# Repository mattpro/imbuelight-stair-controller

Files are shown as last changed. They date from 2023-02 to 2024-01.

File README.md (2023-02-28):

# imbuelight-stair-controller

<!-- Improved compatibility of back to top link: See: https://github.com/othneildrew/Best-README-Template/pull/73 -->

<!--
*** Thanks for checking out the Best-README-Template. If you have a suggestion
*** that would make this better, please fork the repo and create a pull request
*** or simply open an issue with the tag "enhancement".
*** Don't forget to give the project a star!
*** Thanks again! Now go create something AMAZING! :D
-->

<!-- PROJECT SHIELDS -->
<!--
*** I'm using markdown "reference style" links for readability.
*** Reference links are enclosed in brackets [ ] instead of parentheses ( ).
*** See the bottom of this document for the declaration of the reference variables
*** for contributors-url, forks-url, etc. This is an optional, concise syntax you may use.
*** https://www.markdownguide.org/basic-syntax/#reference-style-links
-->
[][contributors-url]
[][forks-url]
[][stars-url]
[][issues-url]
[][license-url]
[][linkedin-url]

<!-- PROJECT LOGO -->
<br />
<div align="center">
  <a href="https://github.com/othneildrew/Best-README-Template">
    
  </a>

  <h3 align="center">Best-README-Template</h3>

  <p align="center">
    An awesome README template to jumpstart your projects!
    <br />
    <a href="https://github.com/othneildrew/Best-README-Template"><strong>Explore the docs »</strong></a>
    <br />
    <br />
    <a href="https://github.com/othneildrew/Best-README-Template">View Demo</a>
    ·
    <a href="https://github.com/othneildrew/Best-README-Template/issues">Report Bug</a>
    ·
    <a href="https://github.com/othneildrew/Best-README-Template/issues">Request Feature</a>
  </p>
</div>

<!-- TABLE OF CONTENTS -->
<details>
  <summary>Table of Contents</summary>
  <ol>
    <li>
      <a href="#about-the-project">About The Project</a>
      <ul>
        <li><a href="#built-with">Built With</a></li>
      </ul>
    </li>
    <li>
      <a href="#getting-started">Getting Started</a>
      <ul>
        <li><a href="#prerequisites">Prerequisites</a></li>
        <li><a href="#installation">Installation</a></li>
      </ul>
    </li>
    <li><a href="#usage">Usage</a></li>
    <li><a href="#roadmap">Roadmap</a></li>
    <li><a href="#contributing">Contributing</a></li>
    <li><a href="#license">License</a></li>
    <li><a href="#contact">Contact</a></li>
    <li><a href="#acknowledgments">Acknowledgments</a></li>
  </ol>
</details>

<!-- ABOUT THE PROJECT -->
## About The Project

[Product Name Screen Shot](https://example.com)

There are many great README templates available on GitHub; however, I didn't find one that really suited my needs so I created this enhanced one. I want to create a README template so amazing that it'll be the last one you ever need -- I think this is it.

Here's why:
* Your time should be focused on creating something amazing. A project that solves a problem and helps others
* You shouldn't be doing the same tasks over and over like creating a README from scratch
* You should implement DRY principles to the rest of your life :smile:

Of course, no one template will serve all projects since your needs may be different. So I'll be adding more in the near future. You may also suggest changes by forking this repo and creating a pull request or opening an issue. Thanks to all the people have contributed to expanding this template!

Use the `BLANK_README.md` to get started.

<p align="right">(<a href="#readme-top">back to top</a>)</p>

### Built With

This section should list any major frameworks/libraries used to bootstrap your project. Leave any add-ons/plugins for the acknowledgements section. Here are a few examples.

* [][Next-url]
* [][React-url]
* [][Vue-url]
* [][Angular-url]
* [][Svelte-url]
* [][Laravel-url]
* [][Bootstrap-url]
* [][JQuery-url]

<p align="right">(<a href="#readme-top">back to top</a>)</p>

<!-- GETTING STARTED -->
## Getting Started

This is an example of how you may give instructions on setting up your project locally.
To get a local copy up and running follow these simple example steps.

### Prerequisites

This is an example of how to list things you need to use the software and how to install them.
* npm
  ```sh
  npm install npm@latest -g
  ```

### Installation

_Below is an example of how you can instruct your audience on installing and setting up your app. This template doesn't rely on any external dependencies or services._

1. Get a free API Key at [https://example.com](https://example.com)
2. Clone the repo
   ```sh
   git clone https://github.com/your_username_/Project-Name.git
   ```
3. Install NPM packages
   ```sh
   npm install
   ```
4. Enter your API in `config.js`
   ```js
   const API_KEY = 'ENTER YOUR API';
   ```

<p align="right">(<a href="#readme-top">back to top</a>)</p>

<!-- USAGE EXAMPLES -->
## Usage

Use this space to show useful examples of how a project can be used. Additional screenshots, code examples and demos work well in this space. You may also link to more resources.

_For more examples, please refer to the [Documentation](https://example.com)_

<p align="right">(<a href="#readme-top">back to top</a>)</p>

<!-- ROADMAP -->
## Roadmap

- [x] Add Changelog
- [x] Add back to top links
- [ ] Add Additional Templates w/ Examples
- [ ] Add "components" document to easily copy & paste sections of the readme
- [ ] Multi-language Support
    - [ ] Chinese
    - [ ] Spanish

See the [open issues](https://github.com/othneildrew/Best-README-Template/issues) for a full list of proposed features (and known issues).

<p align="right">(<a href="#readme-top">back to top</a>)</p>

<!-- CONTRIBUTING -->
## Contributing

Contributions are what make the open source community such an amazing place to learn, inspire, and create. Any contributions you make are **greatly appreciated**.

If you have a suggestion that would make this better, please fork the repo and create a pull request. You can also simply open an issue with the tag "enhancement".
Don't forget to give the project a star! Thanks again!

1. Fork the Project
2. Create your Feature Branch (`git checkout -b feature/AmazingFeature`)
3. Commit your Changes (`git commit -m 'Add some AmazingFeature'`)
4. Push to the Branch (`git push origin feature/AmazingFeature`)
5. Open a Pull Request

<p align="right">(<a href="#readme-top">back to top</a>)</p>

<!-- LICENSE -->
## License

Distributed under the MIT License. See `LICENSE.txt` for more information.

<p align="right">(<a href="#readme-top">back to top</a>)</p>

<!-- CONTACT -->
## Contact

Your Name - [@your_twitter](https://twitter.com/your_username) - email@example.com

Project Link: [https://github.com/your_username/repo_name](https://github.com/your_username/repo_name)

<p align="right">(<a href="#readme-top">back to top</a>)</p>

<!-- ACKNOWLEDGMENTS -->
## Acknowledgments

Use this space to list resources you find helpful and would like to give credit to. I've included a few of my favorites to kick things off!

* [Choose an Open Source License](https://choosealicense.com)
* [GitHub Emoji Cheat Sheet](https://www.webpagefx.com/tools/emoji-cheat-sheet)
* [Malven's Flexbox Cheatsheet](https://flexbox.malven.co/)
* [Malven's Grid Cheatsheet](https://grid.malven.co/)
* [Img Shields](https://shields.io)
* [GitHub Pages](https://pages.github.com)
* [Font Awesome](https://fontawesome.com)
* [React Icons](https://react-icons.github.io/react-icons/search)

<p align="right">(<a href="#readme-top">back to top</a>)</p>

<!-- MARKDOWN LINKS & IMAGES -->
<!-- https://www.markdownguide.org/basic-syntax/#reference-style-links -->
[contributors-shield]: https://img.shields.io/github/contributors/othneildrew/Best-README-Template.svg?style=for-the-badge
[contributors-url]: https://github.com/othneildrew/Best-README-Template/graphs/contributors
[forks-shield]: https://img.shields.io/github/forks/othneildrew/Best-README-Template.svg?style=for-the-badge
[forks-url]: https://github.com/othneildrew/Best-README-Template/network/members
[stars-shield]: https://img.shields.io/github/stars/othneildrew/Best-README-Template.svg?style=for-the-badge
[stars-url]: https://github.com/othneildrew/Best-README-Template/stargazers
[issues-shield]: https://img.shields.io/github/issues/othneildrew/Best-README-Template.svg?style=for-the-badge
[issues-url]: https://github.com/othneildrew/Best-README-Template/issues
[license-shield]: https://img.shields.io/github/license/othneildrew/Best-README-Template.svg?style=for-the-badge
[license-url]: https://github.com/othneildrew/Best-README-Template/blob/master/LICENSE.txt
[linkedin-shield]: https://img.shields.io/badge/-LinkedIn-black.svg?style=for-the-badge&logo=linkedin&colorB=555
[linkedin-url]: https://linkedin.com/in/othneildrew
[product-screenshot]: images/screenshot.png
[Next.js]: https://img.shields.io/badge/next.js-000000?style=for-the-badge&logo=nextdotjs&logoColor=white
[Next-url]: https://nextjs.org/
[React.js]: https://img.shields.io/badge/React-20232A?style=for-the-badge&logo=react&logoColor=61DAFB
[React-url]: https://reactjs.org/
[Vue.js]: https://img.shields.io/badge/Vue.js-35495E?style=for-the-badge&logo=vuedotjs&logoColor=4FC08D
[Vue-url]: https://vuejs.org/
[Angular.io]: https://img.shields.io/badge/Angular-DD0031?style=for-the-badge&logo=angular&logoColor=white
[Angular-url]: https://angular.io/
[Svelte.dev]: https://img.shields.io/badge/Svelte-4A4A55?style=for-the-badge&logo=svelte&logoColor=FF3E00
[Svelte-url]: https://svelte.dev/
[Laravel.com]: https://img.shields.io/badge/Laravel-FF2D20?style=for-the-badge&logo=laravel&logoColor=white
[Laravel-url]: https://laravel.com
[Bootstrap.com]: https://img.shields.io/badge/Bootstrap-563D7C?style=for-the-badge&logo=bootstrap&logoColor=white
[Bootstrap-url]: https://getbootstrap.com
[JQuery.com]: https://img.shields.io/badge/jQuery-0769AD?style=for-the-badge&logo=jquery&logoColor=white
[JQuery-url]: https://jquery.com

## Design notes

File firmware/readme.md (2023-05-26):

## Build in WSL

1. Make sure that env PICO_SDK_PATH is set

```
export PICO_SDK_PATH=../../pico-sdk
```

2. Make directory build 

```
mkdir build
```

3. Run cmake from build directory

```
cd build
cmake ..
```

Example from WSL terminal:
```
/mnt/d/LocalRepo/ImbueLight/imbuelight-stair-controller/firmware/imbuelight_stair_controller_fw/build$ cmake ..
```

4. Build project

```
make
```

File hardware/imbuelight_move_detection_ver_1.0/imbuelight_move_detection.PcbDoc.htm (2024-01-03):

Reporting Options

# File in Previous Format

Date | : | 24.12.2023
Time | : | 13:05:48
Filename | : | D:\LocalRepo\imbue_light\imbuelight-stair-controller\hardware\imbuelight_move_detection_ver_1.0\imbuelight_move_detection.PcbDoc

Version | Warning

This file was generated by an earlier version of the software

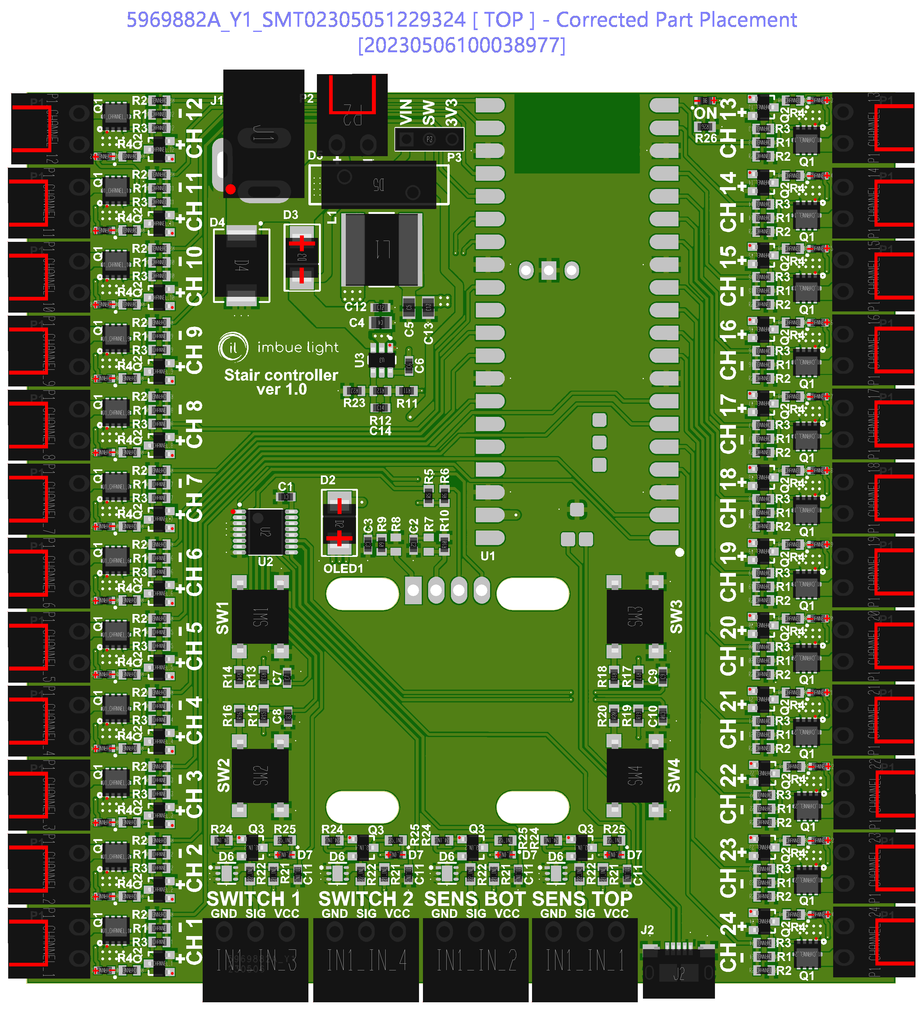
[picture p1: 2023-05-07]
hardware/Production/ver 1.0/Produce_DanZhi.SMT_Snapshot.Top.5969882A_Y1.SMT02305051229324.png

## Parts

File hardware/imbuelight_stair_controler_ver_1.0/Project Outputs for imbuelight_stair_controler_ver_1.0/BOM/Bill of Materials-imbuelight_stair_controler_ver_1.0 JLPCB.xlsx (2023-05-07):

Comment | Designator | Footprint | JLCPCB Part #（optional）
100nF 0603 50V | C1, C2, C3, C6, C7, C8, C9, C10, C11_IN_1, C11_IN_2, C11_IN_3, C11_IN_4, C12 | CAP_0603_High_density | C282519
10uF 0805 50V | C4 | CAP_0805_High_density | C440198
22uF 0805 50V | C5, C13 | CAP_0805_High_density | C98190
56pF 0603 50V | C14 | CAP_0603_High_density | C39148
C205450 | D1_Channel_1, D1_Channel_2, D1_Channel_3, D1_Channel_4, D1_Channel_5, D1_Channel_6, D1_Channel_7, D1_Channel_8, D1_Channel_9, D1_Channel_10, D1_Channel_11, D1_Channel_12, D1_Channel_13, D1_Channel_14, D1_Channel_15, D1_Channel_16, D1_Channel_17, D1_Channel_18, D1_Channel_19, D1_Channel_20, D1_Channel_21, D1_Channel_22, D1_Channel_23, D1_Channel_24, D8 | LED_0603 | C205450
SS24 | D2, D3 | DO214AA | C2845097
SMCJ15CA | D4 | DIOM7959X262N | C720069
C283933 | D5 | SIOV-S14K50 | C283933
C84266 | D7_IN_1, D7_IN_2, D7_IN_3, D7_IN_4 | LED_0603 | C84266
15EDGRC-3.5-3P | IN1_IN_1, IN1_IN_2, IN1_IN_3, IN1_IN_4 | 15EDGRC-3.5 - 3 PIN | C880573
PJ-202BH | J1 | CUI_PJ-202BH | C2851165
10118193-0001LF | J2 | 10118193-0001LF | C482361
NR8040T100M | L1 | INDP8080X42N | C168127
15EDGRC-3.5-2P | P1_Channel_1, P1_Channel_2, P1_Channel_3, P1_Channel_4, P1_Channel_5, P1_Channel_6, P1_Channel_7, P1_Channel_8, P1_Channel_9, P1_Channel_10, P1_Channel_11, P1_Channel_12, P1_Channel_13, P1_Channel_14, P1_Channel_15, P1_Channel_16, P1_Channel_17, P1_Channel_18, P1_Channel_19, P1_Channel_20, P1_Channel_21, P1_Channel_22, P1_Channel_23, P1_Channel_24, P2 | 15EDGRC-3.5 - 2 pin | C61791
HEADER_1X3_2.54_0DEG_THT | P3 | HDR1X3_2.54 | C5360899
AON7410 | Q1_Channel_1, Q1_Channel_2, Q1_Channel_3, Q1_Channel_4, Q1_Channel_5, Q1_Channel_6, Q1_Channel_7, Q1_Channel_8, Q1_Channel_9, Q1_Channel_10, Q1_Channel_11, Q1_Channel_12, Q1_Channel_13, Q1_Channel_14, Q1_Channel_15, Q1_Channel_16, Q1_Channel_17, Q1_Channel_18, Q1_Channel_19, Q1_Channel_20, Q1_Channel_21, Q1_Channel_22, Q1_Channel_23, Q1_Channel_24 | DFN3x3_8L | C269266
BC817-40LT1G | Q2_Channel_1, Q2_Channel_2, Q2_Channel_3, Q2_Channel_4, Q2_Channel_5, Q2_Channel_6, Q2_Channel_7, Q2_Channel_8, Q2_Channel_9, Q2_Channel_10, Q2_Channel_11, Q2_Channel_12, Q2_Channel_13, Q2_Channel_14, Q2_Channel_15, Q2_Channel_16, Q2_Channel_17, Q2_Channel_18, Q2_Channel_19, Q2_Channel_20, Q2_Channel_21, Q2_Channel_22, Q2_Channel_23, Q2_Channel_24, Q3_IN_1, Q3_IN_2, Q3_IN_3, Q3_IN_4 | SOT-23A | C94412
0603 10kOhm 1% | R1_Channel_1, R1_Channel_2, R1_Channel_3, R1_Channel_4, R1_Channel_5, R1_Channel_6, R1_Channel_7, R1_Channel_8, R1_Channel_9, R1_Channel_10, R1_Channel_11, R1_Channel_12, R1_Channel_13, R1_Channel_14, R1_Channel_15, R1_Channel_16, R1_Channel_17, R1_Channel_18, R1_Channel_19, R1_Channel_20, R1_Channel_21, R1_Channel_22, R1_Channel_23, R1_Channel_24, R2_Channel_1, R2_Channel_2, R2_Channel_3, R2_Channel_4, R2_Channel_5, R2_Channel_6, R2_Channel_7, R2_Channel_8, R2_Channel_9, R2_Channel_10, R2_Channel_11, R2_Channel_12, R2_Channel_13, R2_Channel_14, R2_Channel_15, R2_Channel_16, R2_Channel_17, R2_Channel_18, R2_Channel_19, R2_Channel_20, R2_Channel_21, R2_Channel_22, R2_Channel_23, R2_Channel_24, R5, R6, R13, R15, R17, R19, R21_IN_1, R21_IN_2, R21_IN_3, R21_IN_4 | RES_0603 | C3017715
0603 1kOhm 1% | R3_Channel_1, R3_Channel_2, R3_Channel_3, R3_Channel_4, R3_Channel_5, R3_Channel_6, R3_Channel_7, R3_Channel_8, R3_Channel_9, R3_Channel_10, R3_Channel_11, R3_Channel_12, R3_Channel_13, R3_Channel_14, R3_Channel_15, R3_Channel_16, R3_Channel_17, R3_Channel_18, R3_Channel_19, R3_Channel_20, R3_Channel_21, R3_Channel_22, R3_Channel_23, R3_Channel_24, R4_Channel_1, R4_Channel_2, R4_Channel_3, R4_Channel_4, R4_Channel_5, R4_Channel_6, R4_Channel_7, R4_Channel_8, R4_Channel_9, R4_Channel_10, R4_Channel_11, R4_Channel_12, R4_Channel_13, R4_Channel_14, R4_Channel_15, R4_Channel_16, R4_Channel_17, R4_Channel_18, R4_Channel_19, R4_Channel_20, R4_Channel_21, R4_Channel_22, R4_Channel_23, R4_Channel_24, R24_IN_1, R24_IN_2, R24_IN_3, R24_IN_4, R25_IN_1, R25_IN_2, R25_IN_3, R25_IN_4, R26 | RES_0603 | C3016283
RES_0_0402_1_1/16 | R9, R10 | RES_0603 | C21189
0603 49.9Ohm 1% | R11 | RES_0603 | C23185
0603 100kOhm 1% | R12 | RES_0603 | C25803
0603 10Ohm 1% | R14, R16, R18, R20, R22_IN_1, R22_IN_2, R22_IN_3, R22_IN_4 | RES_0603 | C22859
0603 22.1kOhm 1% | R23 | RES_0603 | C137768
SWITCH SMD | SW1, SW2, SW3, SW4 | B3FS-1010 | C231324
PCA9557PW,118 | U2 | TSOP65P640X120-16M | C141380
TPS54202DDCR | U3 | FP-DDC0006A-MFG | C191884

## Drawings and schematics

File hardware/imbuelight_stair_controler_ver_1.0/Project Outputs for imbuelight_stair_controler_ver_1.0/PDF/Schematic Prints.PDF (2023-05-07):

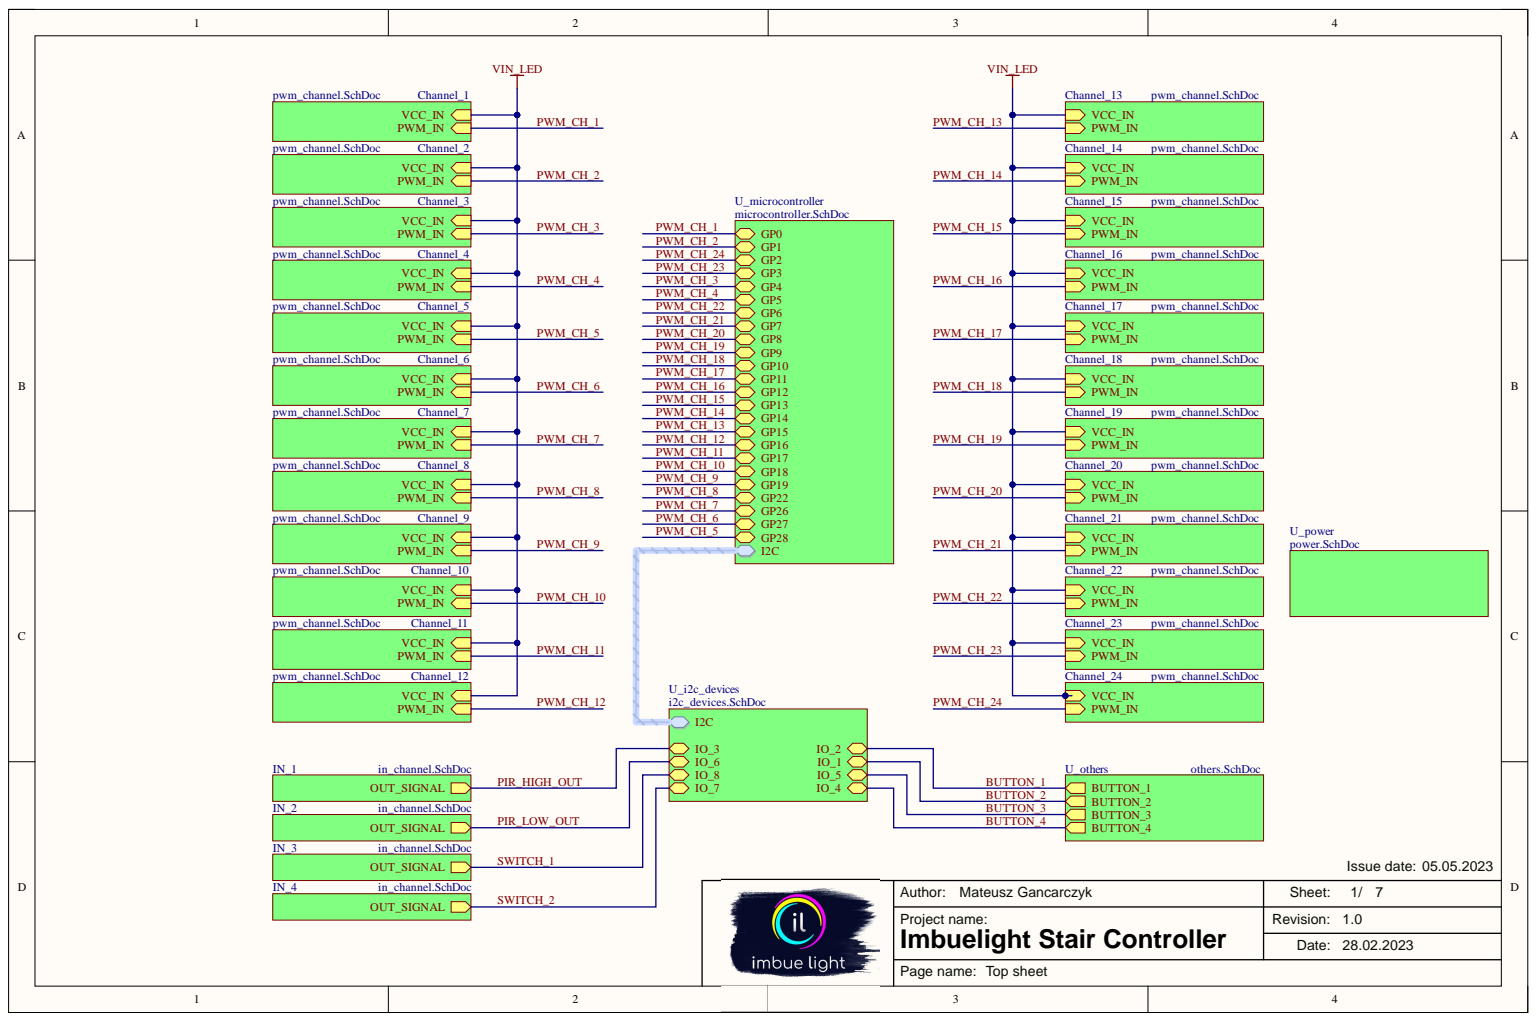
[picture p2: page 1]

OUT_SIGNAL | PIR_HIGH_OUT | BUTTON_1 | BUTTON_1 BUTTON_2 BUTTON_3 BUTTON_4

PIR_LOW_OUT | BUTTON_2

BUTTON_3

OUT_SIGNAL | | BUTTON_4

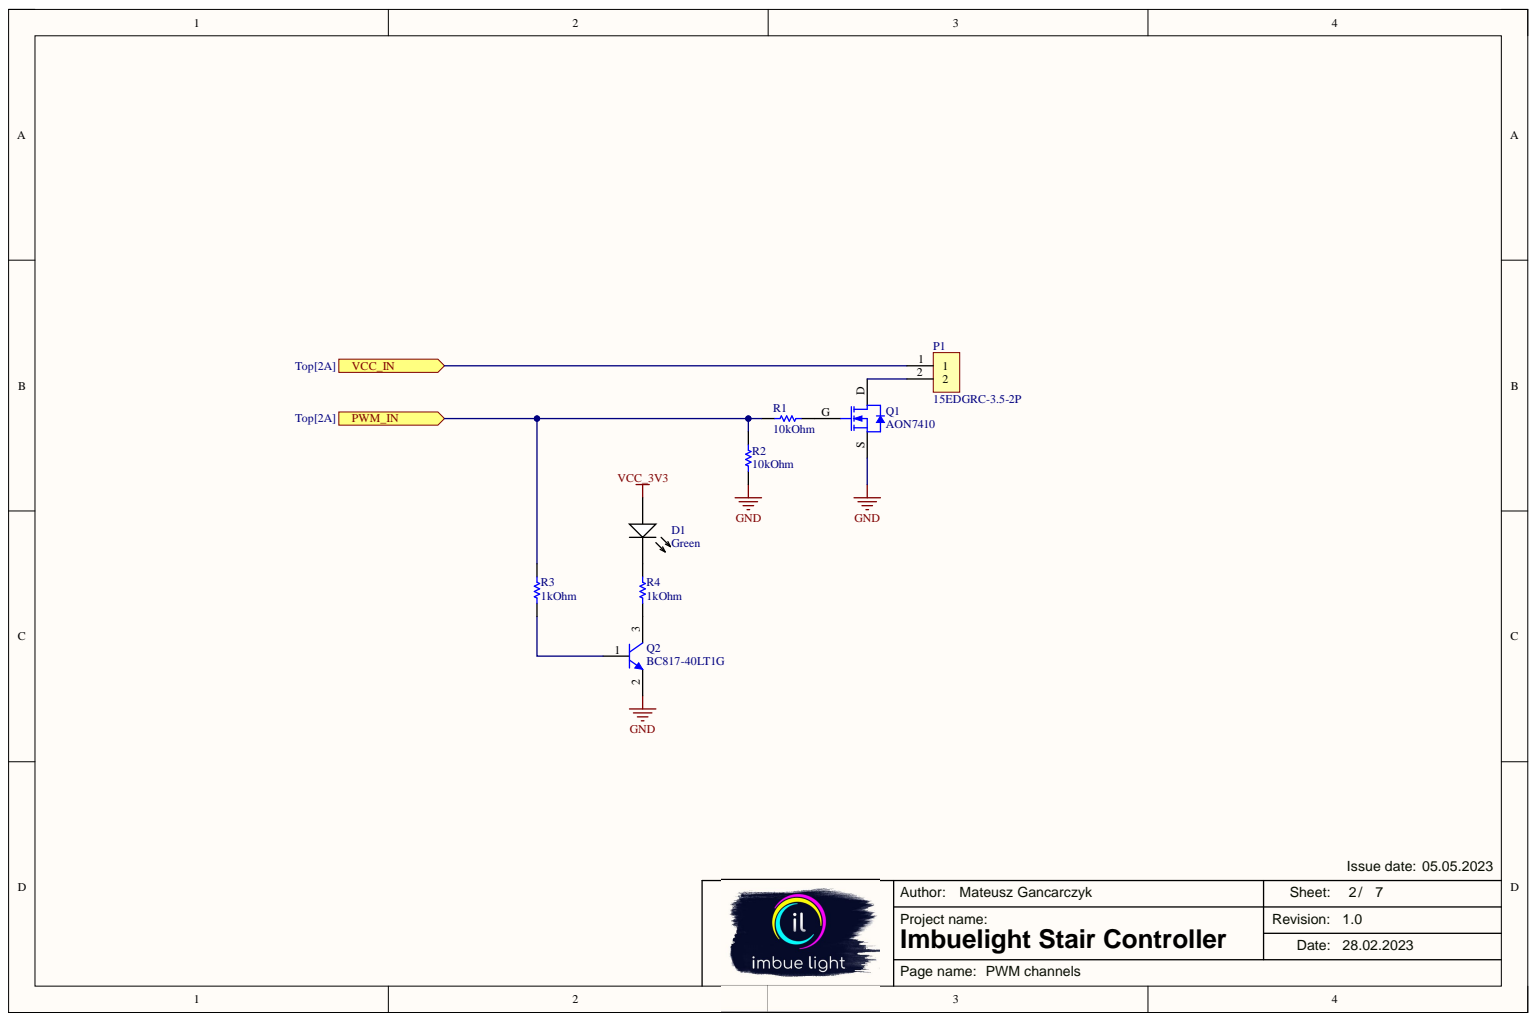
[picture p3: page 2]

Mateusz Gancarczyk
Imbuelight Stair Controller PWM channels

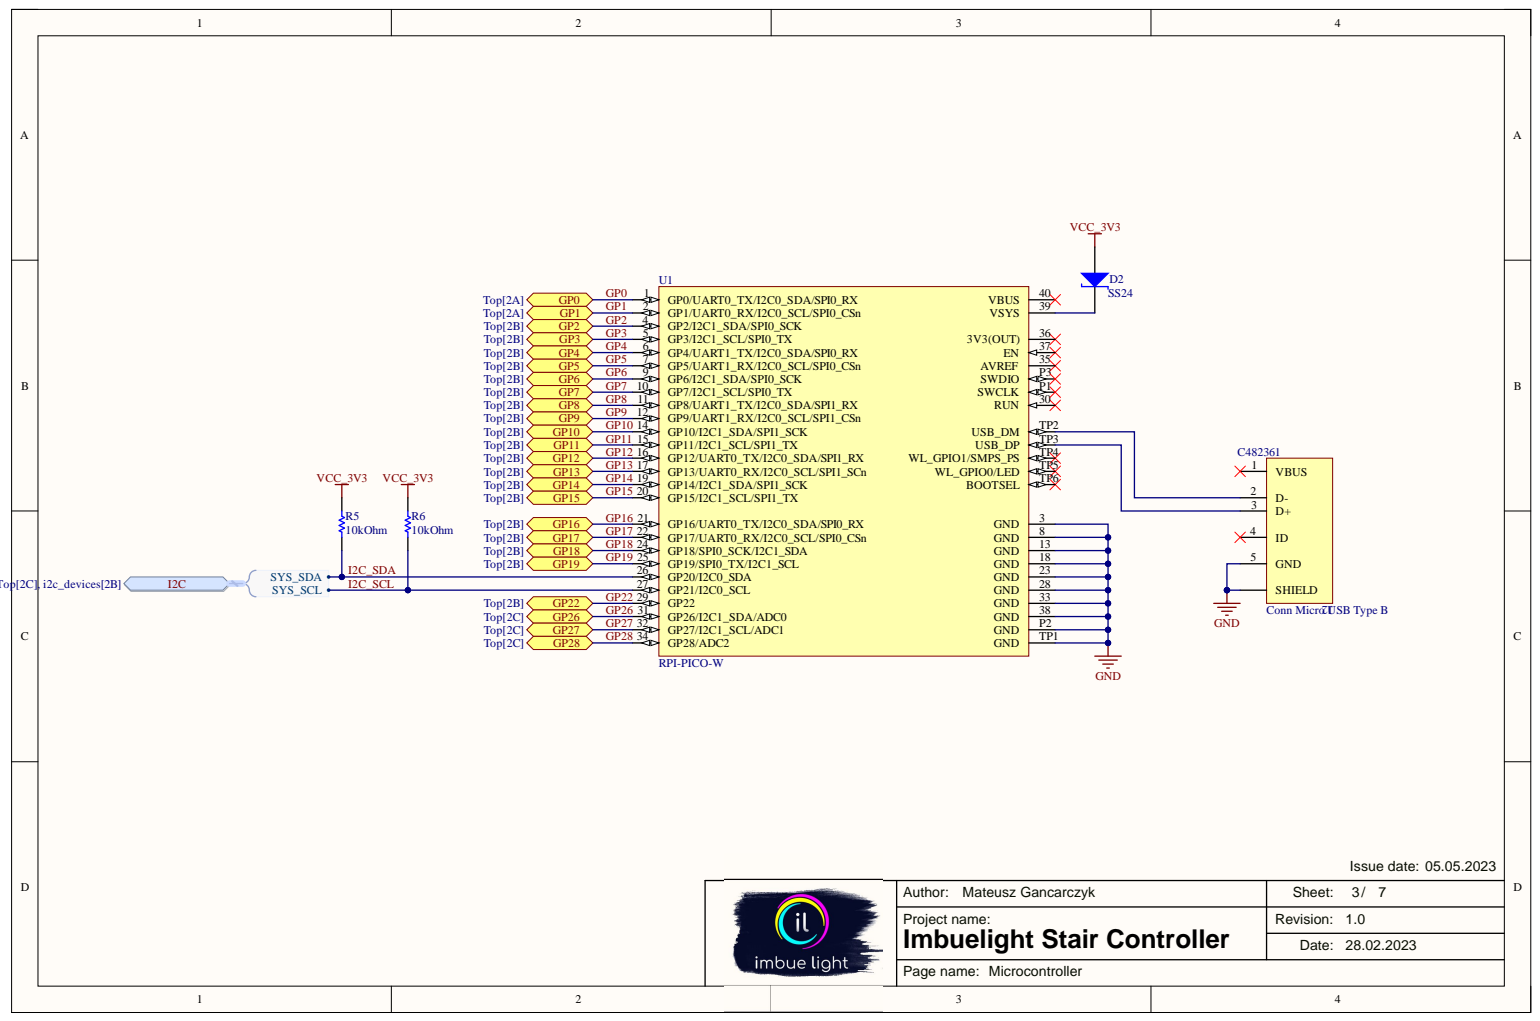
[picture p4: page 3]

T P | 3
T P4

Mateusz Gancarczyk
Imbuelight Stair Controller Microcontroller

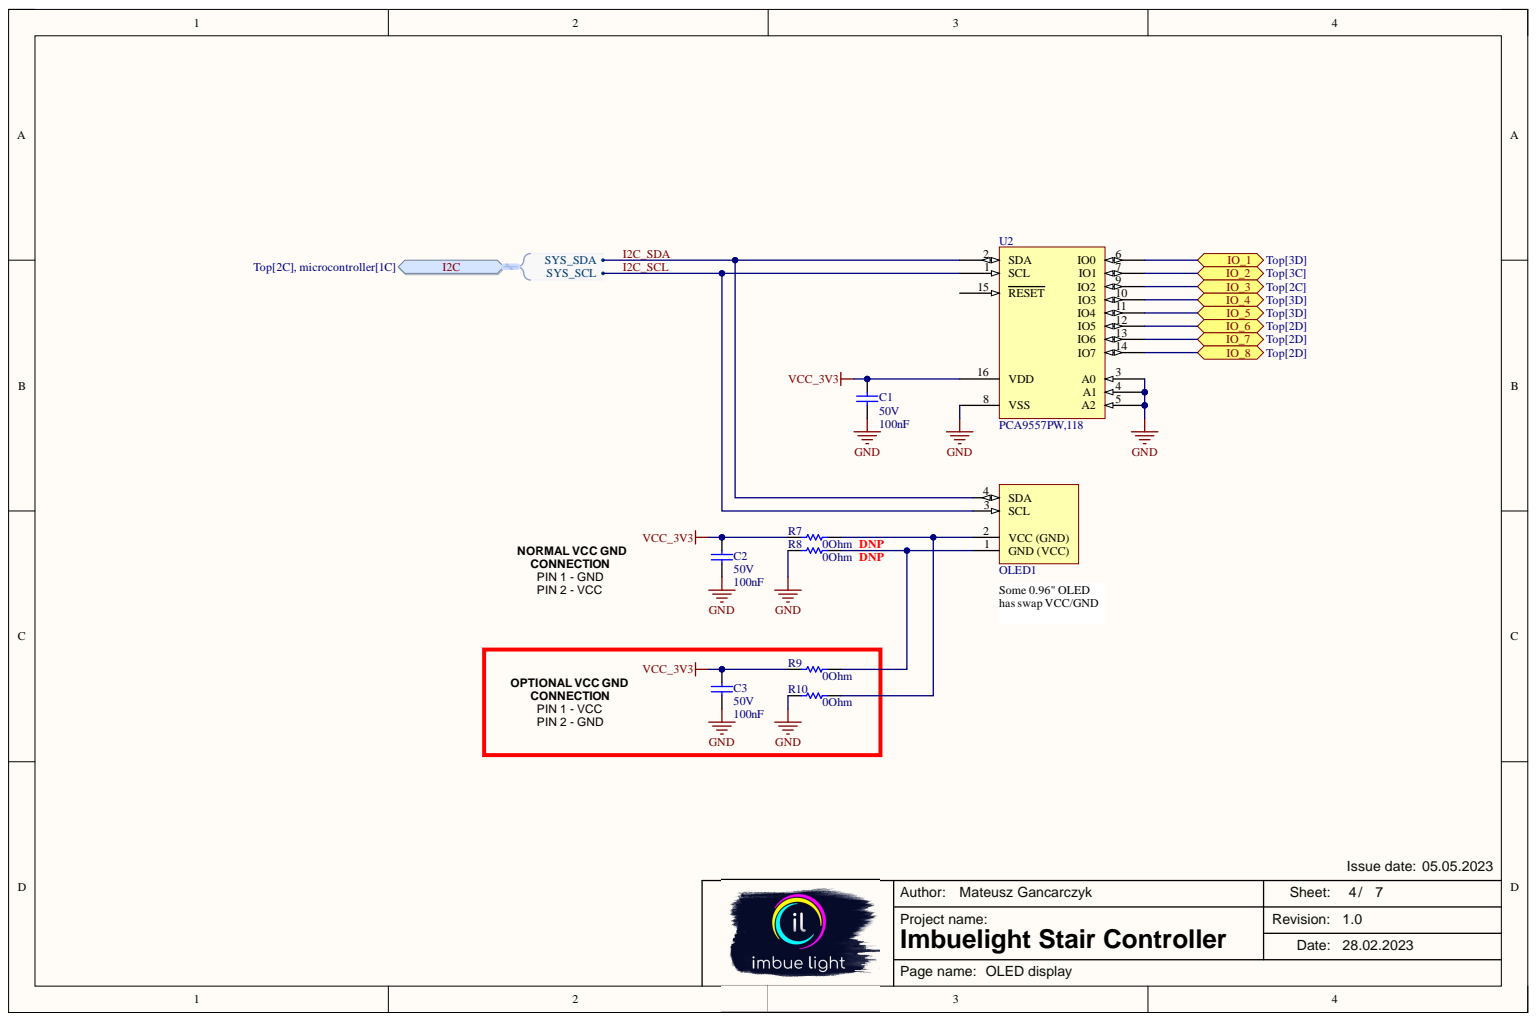
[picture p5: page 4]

OLED1
Some 0.96" OLED
has swap VCC/GND

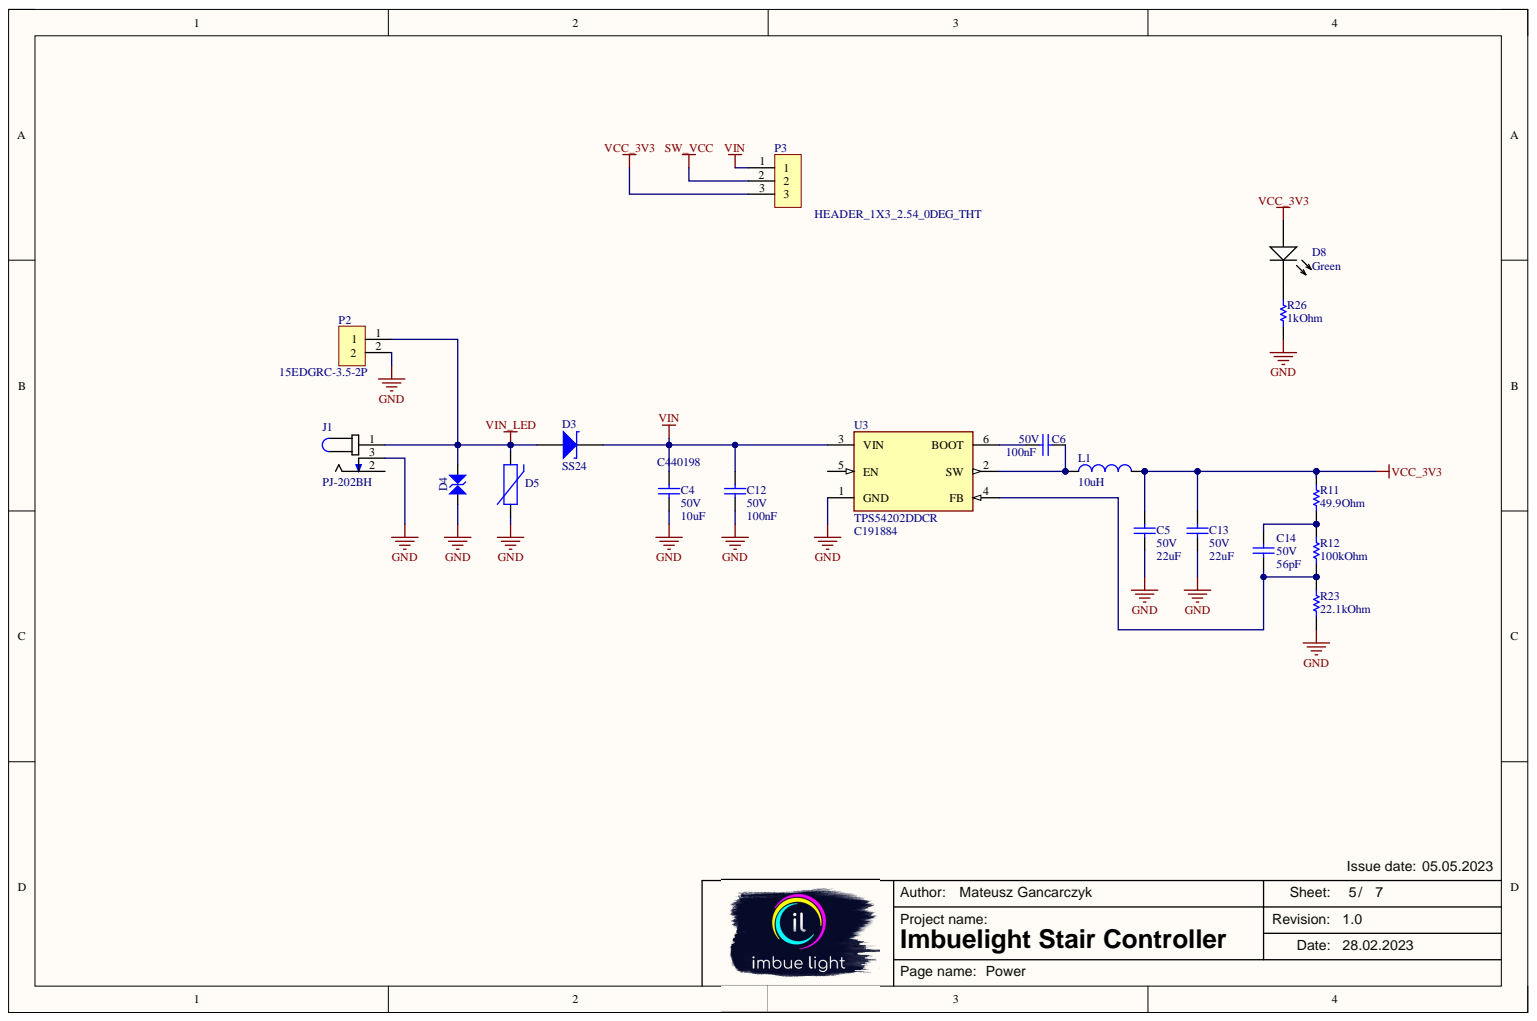
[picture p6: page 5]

Mateusz Gancarczyk
Imbuelight Stair Controller Power

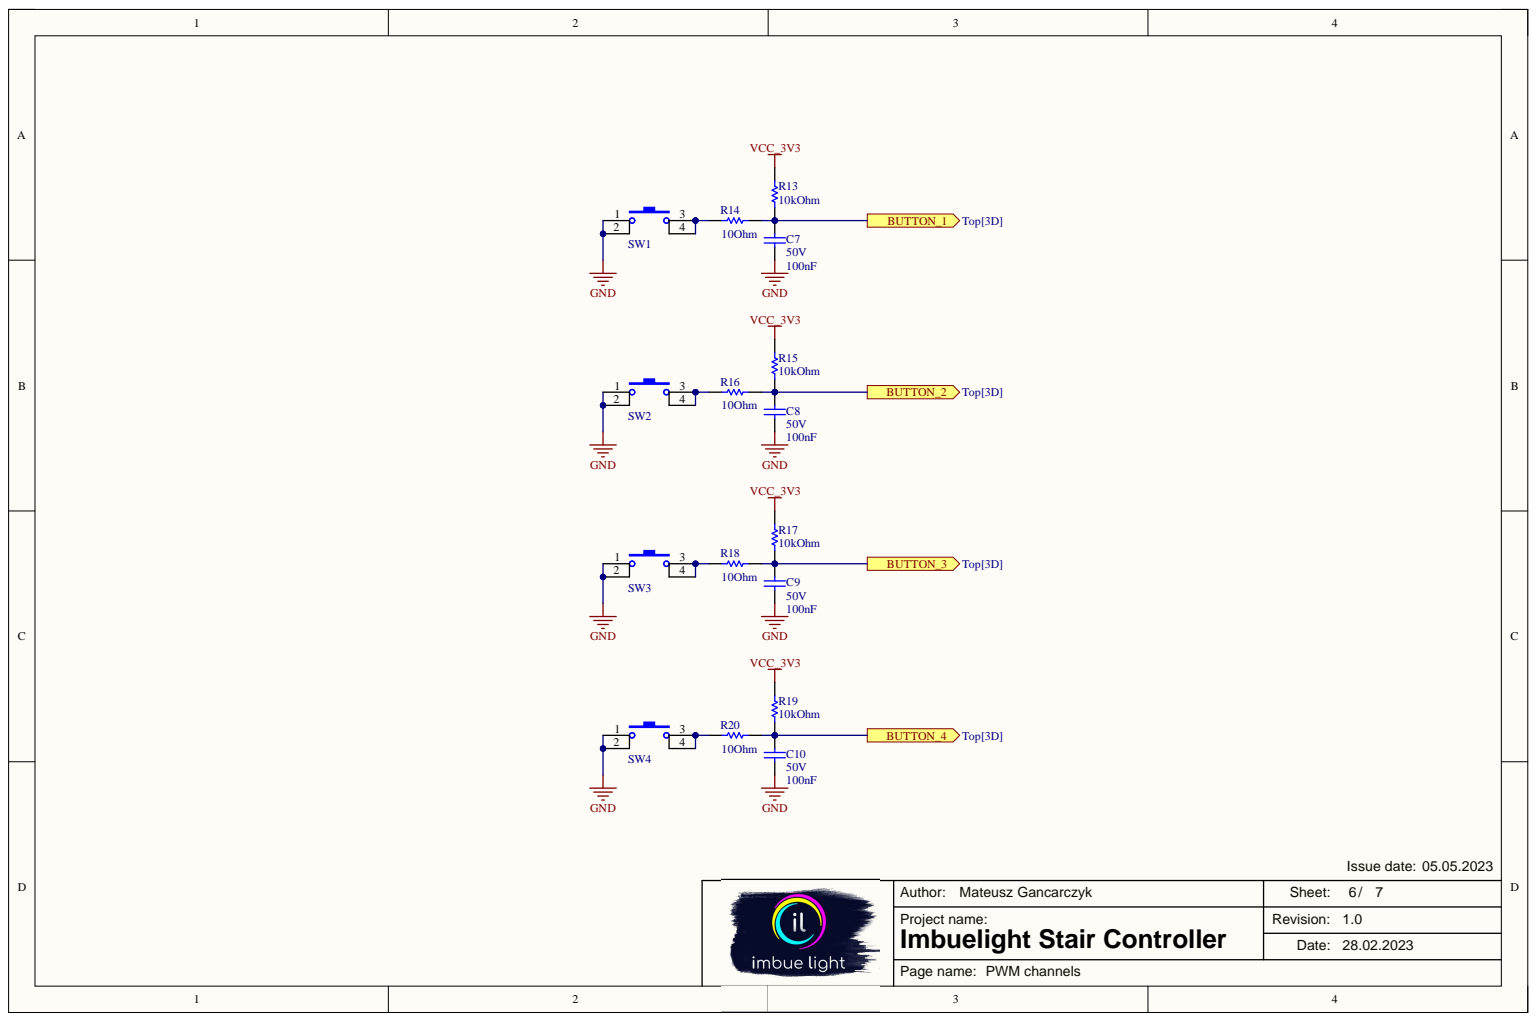
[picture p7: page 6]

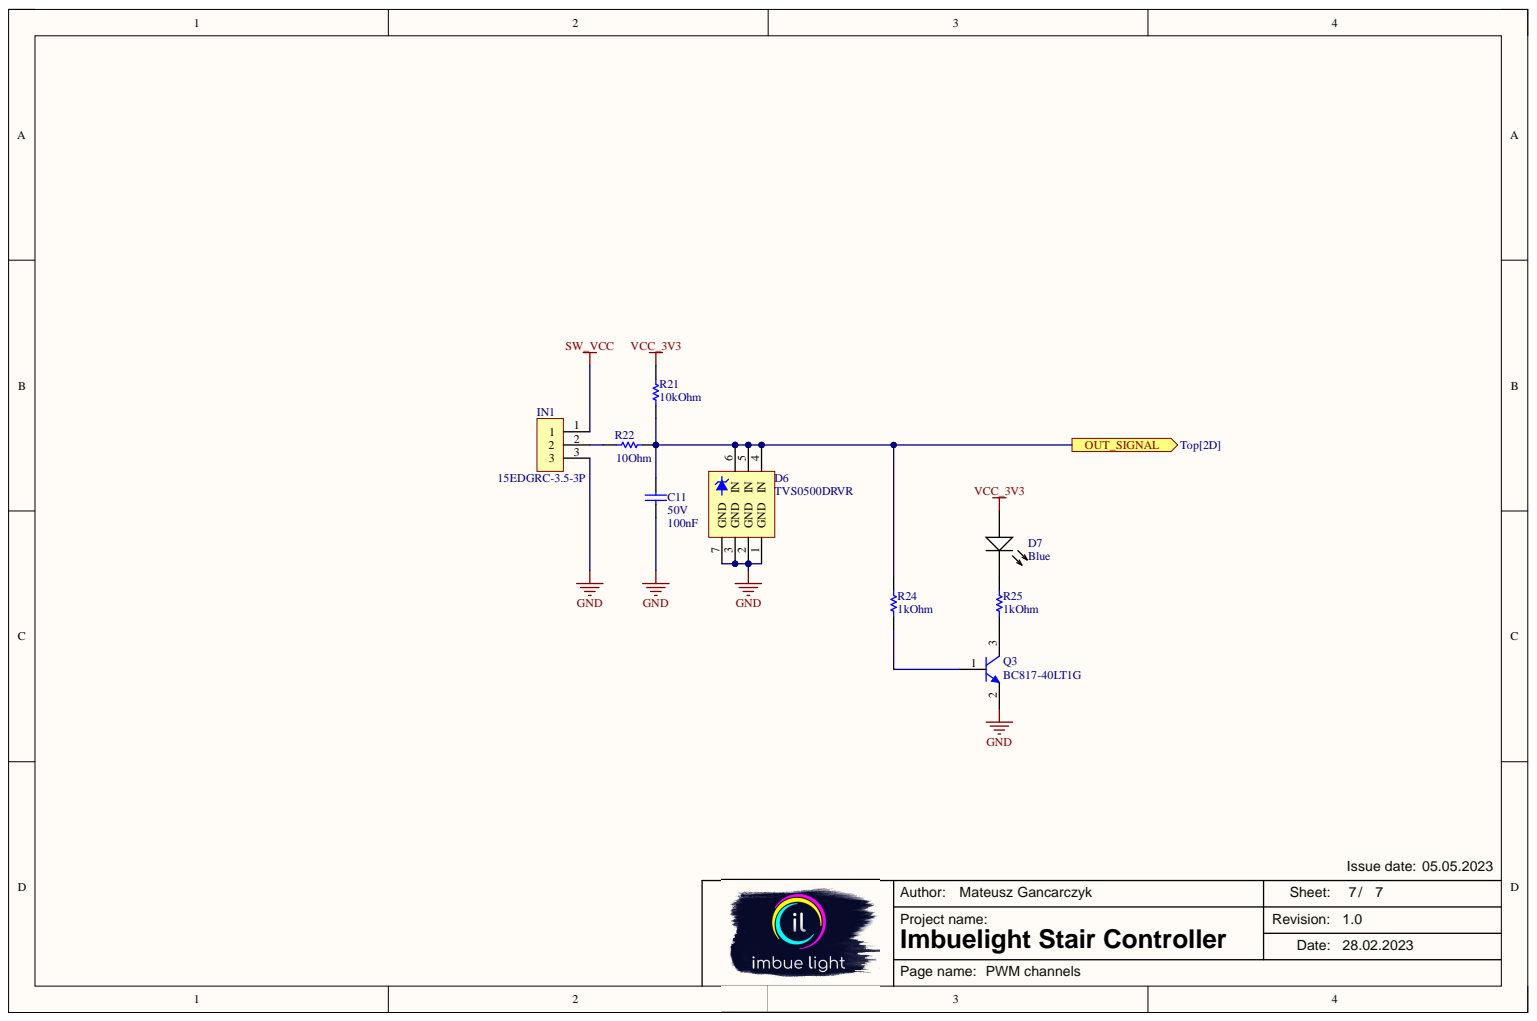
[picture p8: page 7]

IN 4 GND 1 GND 2 GND 3 IN 5 IN 6 GND 7

Mateusz Gancarczyk
Imbuelight Stair Controller PWM channels

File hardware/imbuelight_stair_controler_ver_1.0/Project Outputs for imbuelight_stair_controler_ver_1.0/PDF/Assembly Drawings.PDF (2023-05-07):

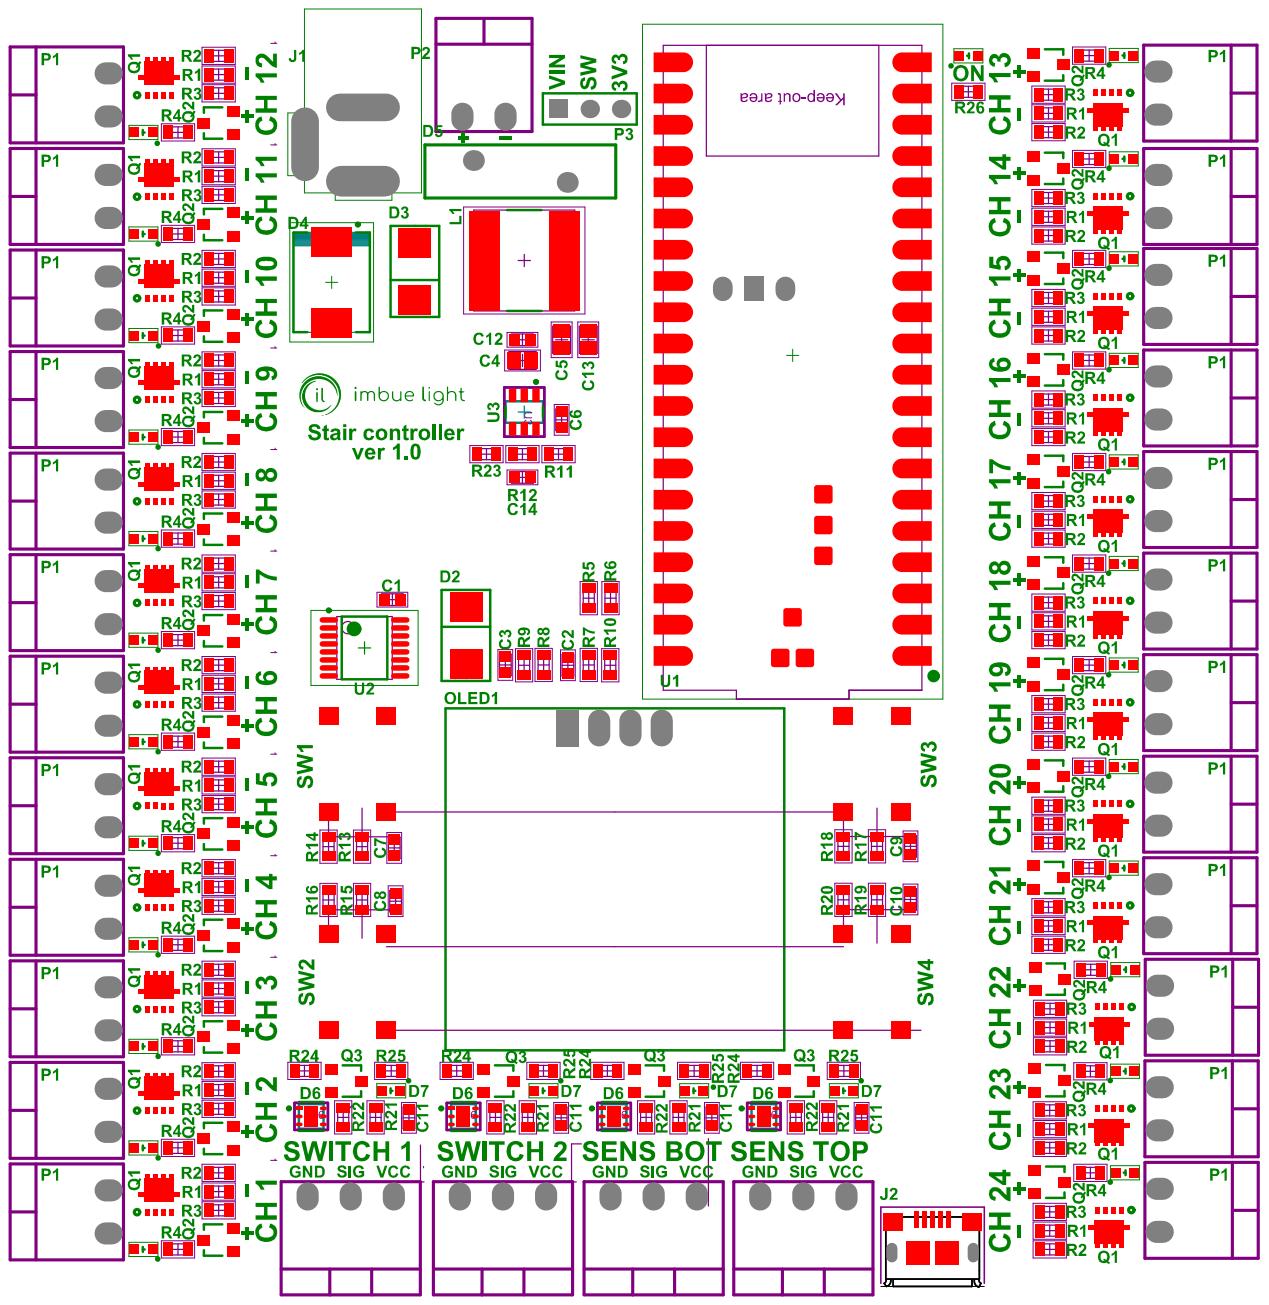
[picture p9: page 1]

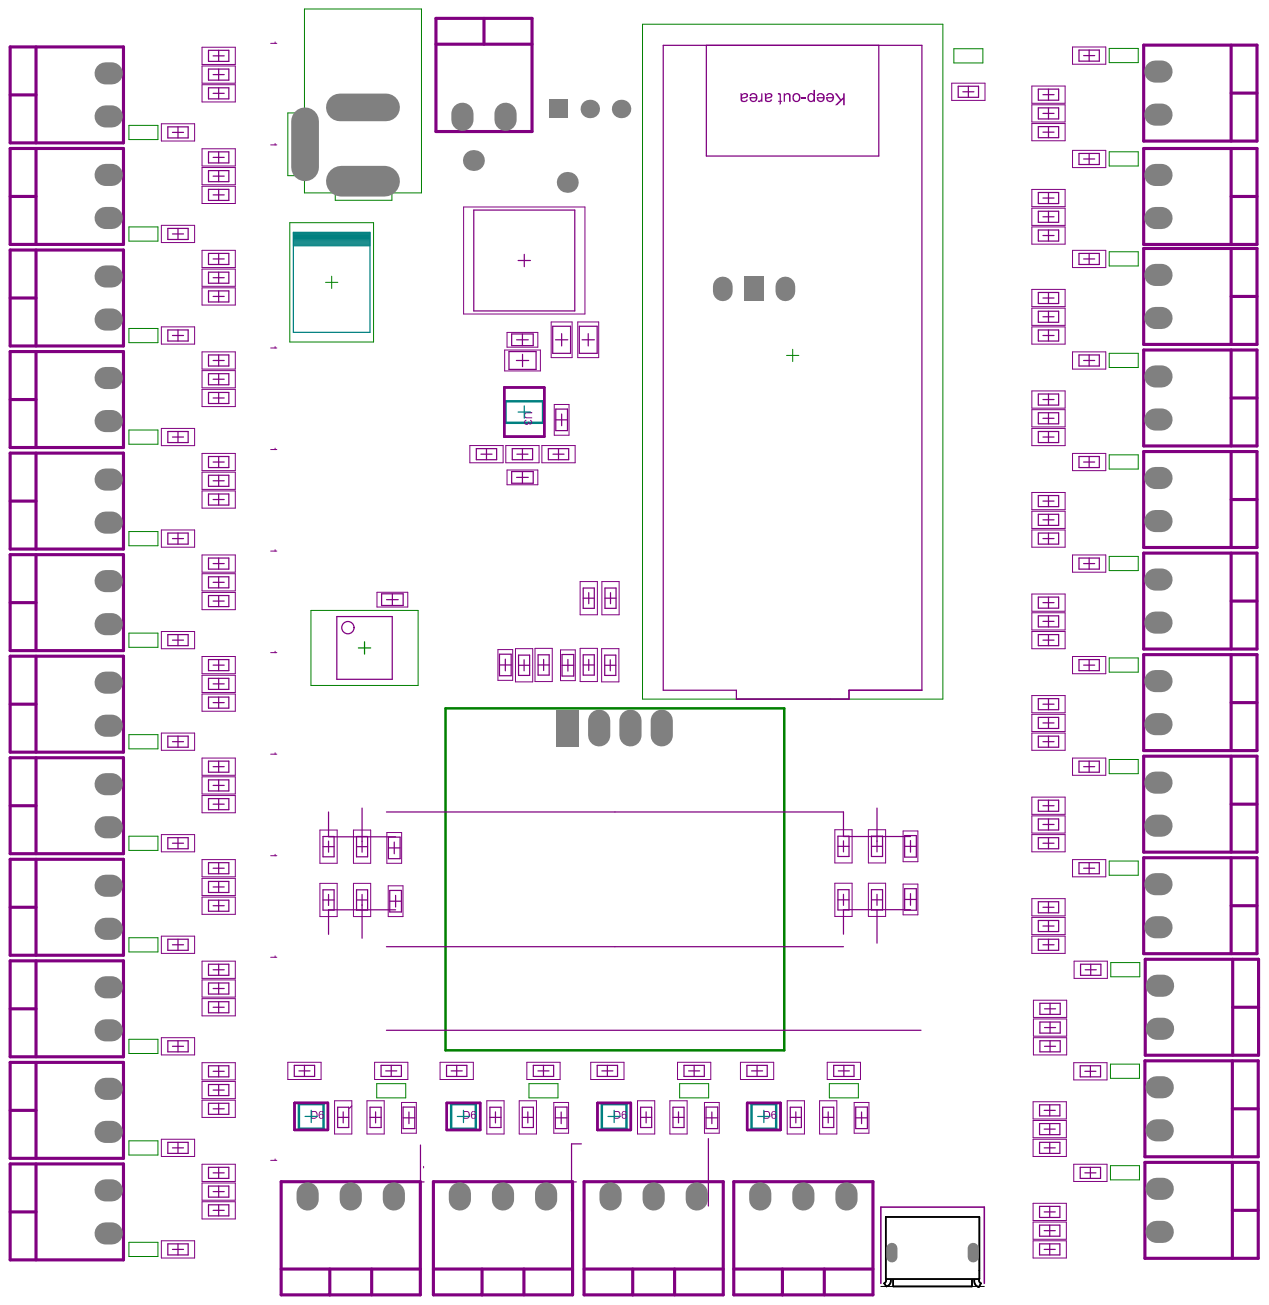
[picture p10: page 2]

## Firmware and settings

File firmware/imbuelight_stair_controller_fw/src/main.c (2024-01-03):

#include "pico/stdlib.h"
#include "hardware/pio.h"
#include "hardware/pwm.h"
#include "pwm.pio.h"
//#include "pico/cyw43_arch.h"
#include "pwm.h"
#include "pwm_pio.h"
#include "config.h"
#include "my_i2c.h"
#include "io_exp.h"
#include "utils.h"
#include "rtt/RTT/SEGGER_RTT.h"


#include "btstack.h"
#include "pico/cyw43_arch.h"
#include "pico/btstack_cyw43.h"
#include "server_common.h"


#define HEARTBEAT_PERIOD_MS 1000


typedef struct {
    bool light_on_flag;
    bool light_on_from_top_flag;
    bool light_on_from_bottom_flag;
    uint32_t light_off_counter;
    effect_dir_t dir;
} light_on_t;


typedef struct {
    uint8_t num_of_stairs;
    uint16_t max_pwm_duty;
    uint32_t stair_light_on_time_ms;
} settings_t;


typedef struct {
    int step;                   // current effect step
    bool enable;                // enable effect
    effect_dir_t dir;           // direction DIR_DOWN_TO_UP or DIR_UP_TO_DOWN
    // settings
    uint16_t increment_step;    // speed of effect
    uint16_t wide;              // wide of effect
    turn_dir_t turn_dir;        // if enable effect goes on or off
} stair_effect_t;



volatile settings_t settings;
volatile light_on_t light_on;

volatile stair_effect_t effect_1;
volatile stair_effect_t effect_2;

struct repeating_timer main_timer;
struct repeating_timer io_pool_timer;

uint16_t counter = 0;


static uint32_t io_exp_pooling_counter = 0;
static volatile bool io_exp_pooling_flag = false;


void effect_1_start(effect_dir_t dir)
{
    effect_1.dir = dir;
    effect_1.step = 0;
    effect_1.turn_dir = TURN_ON;
    effect_1.enable = true;
}

void effect_1_end(effect_dir_t dir)
{
    effect_1.dir = dir;
    effect_1.step = 0;
    effect_1.turn_dir = TURN_OFF;
    effect_1.enable = true;
}

void effect_2_start(void)
{
    effect_2.step = 0;
    effect_2.turn_dir = TURN_ON;
    effect_2.enable = true;
}

void effect_2_end(void)
{
    effect_2.step = 0;
    effect_2.turn_dir = TURN_OFF;
    effect_2.enable = true;
}

bool main_timer_callback(struct repeating_timer *t) // each 2ms
{
    io_exp_pooling_counter ++;
    if ( io_exp_pooling_counter > 50 )
    {
        io_exp_pooling_flag = true;
        io_exp_pooling_counter = 0;
    }

    if ( effect_1.enable )
    {
        uint8_t step_number;
        int calculate_duty;

        effect_1.step += effect_1.increment_step; 

        SEGGER_RTT_WriteString(0,"------------------------------\r\n");

        // Update each step PWM
        for ( int i = 0 ; i < settings.num_of_stairs ; i ++ )
        {
            if      ( effect_1.dir == DIR_UP_TO_DOWN )  step_number = i;
            else if ( effect_1.dir == DIR_DOWN_TO_UP )  step_number = settings.num_of_stairs - i - 1;
            
            if      ( effect_1.turn_dir == TURN_ON  )   calculate_duty = -effect_1.wide*i + effect_1.step;
            else if ( effect_1.turn_dir == TURN_OFF )   calculate_duty = settings.max_pwm_duty + effect_1.wide*i - effect_1.step;

            PWM_set_duty_in_channel_with_gamma_max_duty((pwm_channel_t)step_number, calculate_duty, settings.max_pwm_duty);

            SEGGER_RTT_printf(0, "[%2d]=%d\r\n", i, calculate_duty);
        }

        // Check ending condition
        if ( ( effect_1.turn_dir == TURN_ON  ) && ( calculate_duty > settings.max_pwm_duty ) )
        {
            SEGGER_RTT_WriteString(0,"Effect animation disable after turn on\r\n");
            effect_1.enable = false;
        }
        else if ( ( effect_1.turn_dir == TURN_OFF ) && ( calculate_duty < 0 ) )
        {
            SEGGER_RTT_WriteString(0,"Effect animation disable after turn off\r\n");
            effect_1.enable = false;
            light_on.light_on_from_top_flag = false; 
            light_on.light_on_from_bottom_flag = false; 
        }
    }

    if ( effect_2.enable )
    {
        effect_2.step += effect_2.increment_step;

        for ( int i = 0 ; i < settings.num_of_stairs ; i ++ )
        {
            if ( effect_2.turn_dir == TURN_ON )
            {
                PWM_set_duty_in_channel_with_gamma((pwm_channel_t)i,  effect_2.step );
            }
            else if ( effect_2.turn_dir == TURN_OFF )
            {
                PWM_set_duty_in_channel_with_gamma((pwm_channel_t)i,  settings.max_pwm_duty - effect_2.step );
            }
        }

        // End effect condition
        if ( ( effect_2.turn_dir == TURN_ON ) && (  effect_2.step > settings.max_pwm_duty ) )
        {
            effect_2.enable = false;
        }
        if ( ( effect_2.turn_dir == TURN_OFF ) && (  effect_2.step < 0 ) )
        {
            effect_2.enable = false;
        }
    }

    if ( ( light_on.light_on_flag == true ) && ( ( light_on.light_on_from_top_flag == true ) || ( light_on.light_on_from_bottom_flag == true ) ) )
    {
        light_on.light_off_counter ++;
        if ( light_on.light_off_counter > settings.stair_light_on_time_ms/2 ) // time diveded by 2 because loop interval is 2ms
        {
            SEGGER_RTT_WriteString(0,"Light exit\r\n");
            light_on.dir == DIR_UP_TO_DOWN ? effect_1_end(DIR_UP_TO_DOWN) : effect_1_end(DIR_DOWN_TO_UP);
            //effect_2_end();
            light_on.light_on_flag = false;
            light_on.light_off_counter = 0;
        }  
    }   

    return true;
}


void sens_top_enter(void)
{
    SEGGER_RTT_WriteString(0,"Sensor top enter\r\n");   
    light_on.light_off_counter = 0;
    light_on.light_on_from_top_flag = false;
    if ( ( light_on.light_on_from_top_flag == false ) && ( light_on.light_on_flag == false ) )
    {
        SEGGER_RTT_WriteString(0,"Light enter\r\n");
        light_on.light_on_flag = true;
        light_on.dir = DIR_UP_TO_DOWN;
        effect_1_start(light_on.dir);
        //effect_2_start();
    }  
}

void sens_top_exit(void)
{
    light_on.light_on_from_top_flag = true;
    SEGGER_RTT_WriteString(0,"Sensor top exit\r\n");   
}

void sens_bottom_enter(void)
{
    SEGGER_RTT_WriteString(0,"Sensor bottom enter\r\n");
    light_on.light_off_counter = 0;
    light_on.light_on_from_bottom_flag = false;
    if ( ( light_on.light_on_from_bottom_flag == false ) && ( light_on.light_on_flag == false ) )
    {
        SEGGER_RTT_WriteString(0,"Light enter\r\n");
        light_on.light_on_flag = true;
        light_on.dir = DIR_DOWN_TO_UP;
        effect_1_start(light_on.dir);
        //effect_2_start();
    }  
}

void sens_bottom_exit(void)
{
    light_on.light_on_from_bottom_flag = true;
    SEGGER_RTT_WriteString(0,"Sensor bottom exit\r\n"); 
}

bool led_state = false;


// Related to bluetooth
static btstack_timer_source_t heartbeat;
static btstack_packet_callback_registration_t hci_event_callback_registration;

static void heartbeat_handler(struct btstack_timer_source *ts) 
{
    static uint32_t counter = 0;
    counter++;

    // // Update the temp every 10s
    // if (counter % 10 == 0) {
    //     poll_temp();
    //     if (le_notification_enabled) {
    //         att_server_request_can_send_now_event(con_handle);
    //     }
    // }

    // Invert the led
    static int led_on = true;
    led_on = !led_on;
    cyw43_arch_gpio_put(CYW43_WL_GPIO_LED_PIN, led_on);

    // Restart timer
    btstack_run_loop_set_timer(ts, HEARTBEAT_PERIOD_MS);
    btstack_run_loop_add_timer(ts);
}



int main() 
{
    stdio_init_all();
    start_blink_led();

    SEGGER_RTT_WriteString(0,"############################################\r\n");
    SEGGER_RTT_WriteString(0,"### IMBUE LIGHT STAIR CONTROLLER VER 1.1 ###\r\n");
    SEGGER_RTT_printf(0, "###         %s %s         ###\r\n", __DATE__, __TIME__);
    SEGGER_RTT_WriteString(0,"############################################\r\n");


    // STAIR Settings
    settings.num_of_stairs = 18;
    settings.max_pwm_duty = (uint16_t)(0.1*MAX_PWM_DUTY);
    settings.stair_light_on_time_ms = 13000;

    // Effect 1 settings
    effect_1.enable = false;
    effect_1.increment_step = 10;
    effect_1.wide = 2000;
    effect_1.dir = DIR_DOWN_TO_UP;

    // Effect 2 settings
    effect_2.enable = false;
    effect_2.increment_step = 10;
    effect_2.dir = DIR_DOWN_TO_UP;


    PWM_HW_init();
    PWM_PIO_init();
    I2C_init();
    IO_EXP_init();
    IO_EXP_reg_event_sens_top_cbfunc(sens_top_enter, sens_top_exit);
    IO_EXP_reg_event_sens_bottom_cbfunc(sens_bottom_enter, sens_bottom_exit);
    add_repeating_timer_us(-2000, main_timer_callback, NULL, &main_timer);

    SEGGER_RTT_printf(0,"Boot ok\r\n");


// Related to bluetooth

// initialize CYW43 driver architecture (will enable BT if/because CYW43_ENABLE_BLUETOOTH == 1)
    if (cyw43_arch_init()) 
    {
        printf("failed to initialise cyw43_arch\n");
        return -1;
    }

    l2cap_init();
    sm_init();

    att_server_init(profile_data, att_read_callback, att_write_callback);    

    // inform about BTstack state
    hci_event_callback_registration.callback = &packet_handler;
    hci_add_event_handler(&hci_event_callback_registration);

    // register for ATT event
    att_server_register_packet_handler(packet_handler);

    // set one-shot btstack timer
    heartbeat.process = &heartbeat_handler;
    btstack_run_loop_set_timer(&heartbeat, HEARTBEAT_PERIOD_MS);
    btstack_run_loop_add_timer(&heartbeat);

    // turn on bluetooth!
    hci_power_control(HCI_POWER_ON);
    
    //btstack_run_loop_execute();


    while(1)
    {
        static uint32_t counter = 0;

        if ( io_exp_pooling_flag == true)
        { 
            io_exp_pooling_flag = false;
            counter++;
            SEGGER_RTT_printf(0,"pooling io exp. C: %4d enable:%d light off counter: %d\r\n", counter, effect_1.enable, light_on.light_off_counter);
            IO_EXP_pooling();
        }
    }
}

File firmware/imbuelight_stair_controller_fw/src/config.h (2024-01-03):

#ifndef __CONFIG_H
#define __CONFIG_H

#include "rtt/RTT/SEGGER_RTT.h"

// SETTINGS
#define GAMMA_FACTOR 4.0f

// ENUM
typedef enum {
    DIR_DOWN_TO_UP,
    DIR_UP_TO_DOWN
} effect_dir_t;

typedef enum {
    TURN_ON,
    TURN_OFF
} turn_dir_t;


// PINOUT
// Standard PWM
#define PWM_CHANNEL_1_PIN       0   // Slice: 0 CH: A
#define PWM_CHANNEL_2_PIN       1   // Slice: 0 CH: B
#define PWM_CHANNEL_10_PIN      18   // Slice: 1 CH: A    SLICE 1A moze byc albo pin 2 lub 18 // kanał 24 trzeba usunąć - pinu 2 nie moge użyć
#define PWM_CHANNEL_23_PIN      3   // Slice: 1 CH: B  
#define PWM_CHANNEL_3_PIN       4   // Slice: 2 CH: A
#define PWM_CHANNEL_4_PIN       5   // Slice: 2 CH: B
#define PWM_CHANNEL_22_PIN      6   // Slice: 3 CH: A
#define PWM_CHANNEL_21_PIN      7   // Slice: 3 CH: B
#define PWM_CHANNEL_20_PIN      8   // Slice: 4 CH: A
#define PWM_CHANNEL_19_PIN      9   // Slice: 4 CH: B`
#define PWM_CHANNEL_18_PIN      10  // Slice: 5 CH: A
#define PWM_CHANNEL_17_PIN      11  // Slice: 5 CH: B
#define PWM_CHANNEL_16_PIN      12  // Slice: 6 CH: A
#define PWM_CHANNEL_15_PIN      13  // Slice: 6 CH: B
#define PWM_CHANNEL_14_PIN      14  // Slice: 7 CH: A
#define PWM_CHANNEL_13_PIN      15  // Slice: 7 CH: B

// PWM from PIO 0
#define PIO_CHANNEL_5_8       pio0
#define PWM_CHANNEL_5_PIN       28 
#define PWM_CHANNEL_6_PIN       27 
#define PWM_CHANNEL_7_PIN       26 
#define PWM_CHANNEL_8_PIN       22 

// PWM from PIO 1
#define PIO_CHANNEL_9_12       pio1
#define PWM_CHANNEL_9_PIN       19 
#define PWM_CHANNEL_11_PIN      17
#define PWM_CHANNEL_12_PIN      16 

// I2C pin
#define I2C_SDA_PIN             20
#define I2C_SCL_PIN             21

#endif

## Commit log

2023-02-28 Initial hardware project
    [Top.SchDoc, imbuelight_stair_controler_ver_1.0.PrjPcb, microcontroller.SchDoc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]
2023-03-04 Update sheets.
    [imbuelight_stair_controler_ver_1.0.PrjPcb, others.SchDoc, power.SchDoc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]
2023-03-11 Update docs. Add in channel. Add rpi pico w module.
    [Top.SchDoc, imbuelight_stair_controler_ver_1.0.PrjPcb, in_channel.SchDoc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]
2023-03-28 Add blink led example.
2023-03-29 Add PWM using pio example.
2023-03-29 Update PWM to 4 channel.
2023-03-30 Add 24 PWM channel example. Working on PCB and schematic.
    [Top.SchDoc, i2c_devices.SchDoc, imbuelight_stair_controler_ver_1.0.PrjPcb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]
2023-04-02 Update hardware project
    [imbuelight_stair_controler_ver_1.0.PrjPcb, pwm_channel.SchDoc]
2023-04-16 Update PCB and schematic.
    [Top.SchDoc, imbuelight_stair_controler_ver_1.0.PrjPcb, microcontroller.SchDoc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]
2023-04-24 Update PCB
    [Top.SchDoc, imbuelight_stair_controler_ver_1.0.PrjPcb]
2023-05-03 Update PCB and schematics.
    [i2c_devices.SchDoc, in_channel.SchDoc, microcontroller.SchDoc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]
2023-05-07 Add production files for version 1.0
    [Bill of Materials-imbuelight_stair_controler_ver_1.0 JLPCB.xlsx, Bill of Materials-imbuelight_stair_controler_ver_1.0.csv, Bill of Materials-imbuelight_stair_c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]
2023-05-22 Start working on PWM.
2023-05-26 Add project configuration for vs code. Unification PWM from HW and PIO implementation. Set PWM frequency to 2.538kHz and max duty to 0x3FFF (16383) - 14 bit. Add i2c module wit SSD 1306 library. Star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
2023-05-27 Add prototype of effect 2.
2023-05-28 Add move detection hw project.
    [imbuelight_move_detection.PcbDoc, imbuelight_move_detection.SchDoc, imbuelight_move_detection_ver_1.0.PrjPcb]
2023-06-01 Update move sensor project.
    [imbuelight_move_detection.PcbDoc, imbuelight_move_detection.SchDoc, imbuelight_move_detection_ver_1.0.PrjPcb]
2023-06-13 Add production files for move detection board.
    [imbuelight_move_detection — panel.GBL, imbuelight_move_detection — panel.GBO, imbuelight_move_detection — panel.GBP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]
2023-07-26 Add usb stdio output. Add basic pooling of i2c expander pooling.
2023-07-27 Refactor i2c module. Add io exp lib.
2023-07-31 Working on move controller ver 2.0.
    [imbuelight_move_detection.PcbDoc, imbuelight_move_detection.SchDoc]
2024-01-03 Fix problem with duty less then max.
    [SEGGER_RTT.h]
